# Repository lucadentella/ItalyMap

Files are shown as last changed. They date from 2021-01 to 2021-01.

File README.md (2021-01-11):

# ItalyMap
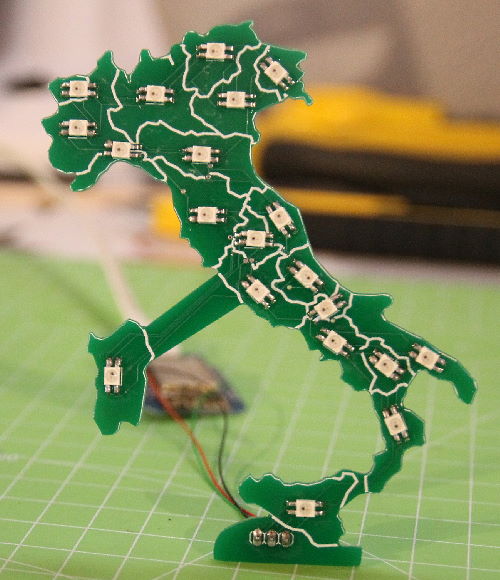
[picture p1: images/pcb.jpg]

## Description / *Descrizione*
ItalyMap is an electronic project to create a dynamic map of Italy. Thanks to the use of RGB LEDs, one for each Italian region, it is possible to give a visual representation of data relating to these regions.

*ItalyMap è un progetto elettronico per realizzare una mappa dell'Italia dinamica. Grazie all'uso di led RGB, uno per ogni regione italiana, è possibile dare una rappresentazione visuale di dati relativi a tali regioni.*
## Folders / *Cartelle*
 - **eagle**, project in Autodesk Eagle format / *progetto in formato Autodesk Eagle*
 - **gerber**, gerber files ready for manufacturing (JLCPCB service) / *files gerber pronti per la produzione (service JLCPCB)*
 - **sketch**, Arduino programs (esp8266 board) / *programmi Arduino (scheda esp8266)*
 	 - Test_Italian-Flag, displays italian flag / *visualizza la bandiera italiana*
	 - Covid_NewCases-perRegion, displays the new Covid-19 cases / *visualizza i nuovi casi di Covid-19*
	 - Covid_VaccinationRate-perRegion, displays the vaccination rate / *visualizza il numero di vaccinazioni*
## Partlist / *Elenco componenti*
 - [SK6812 MINI-E](https://www.aliexpress.com/item/4000475685852.html) addressable LED
 - 1x03 pinhead
 - Wemos D1 Mini (to run Arduino example)
### Test_Italian-Flag:
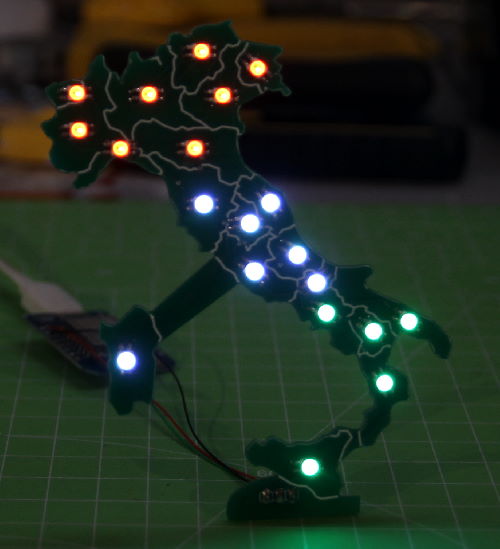
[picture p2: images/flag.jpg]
 
### Covid_NewCases-perRegion:
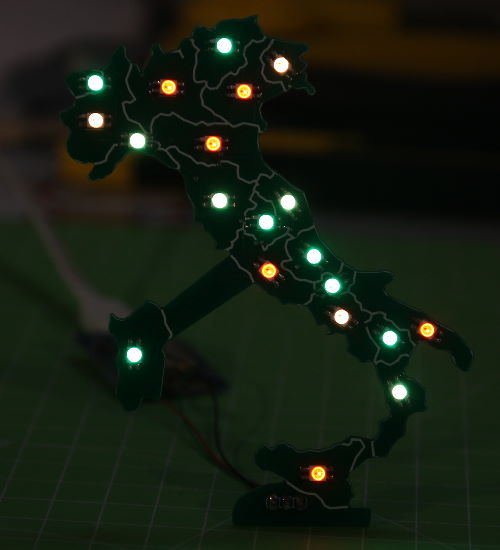
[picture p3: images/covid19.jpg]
 
### Covid_VaccinationRate-perRegion:
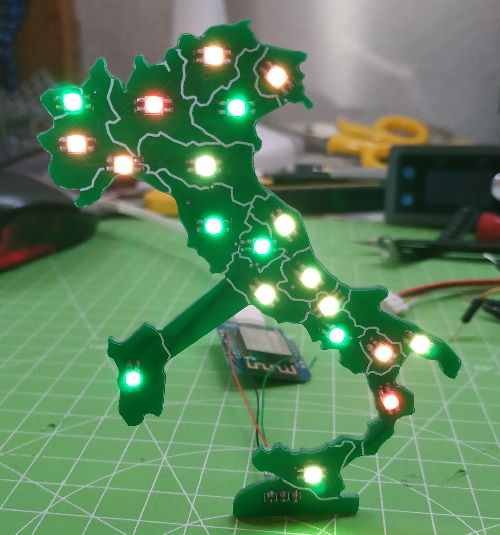
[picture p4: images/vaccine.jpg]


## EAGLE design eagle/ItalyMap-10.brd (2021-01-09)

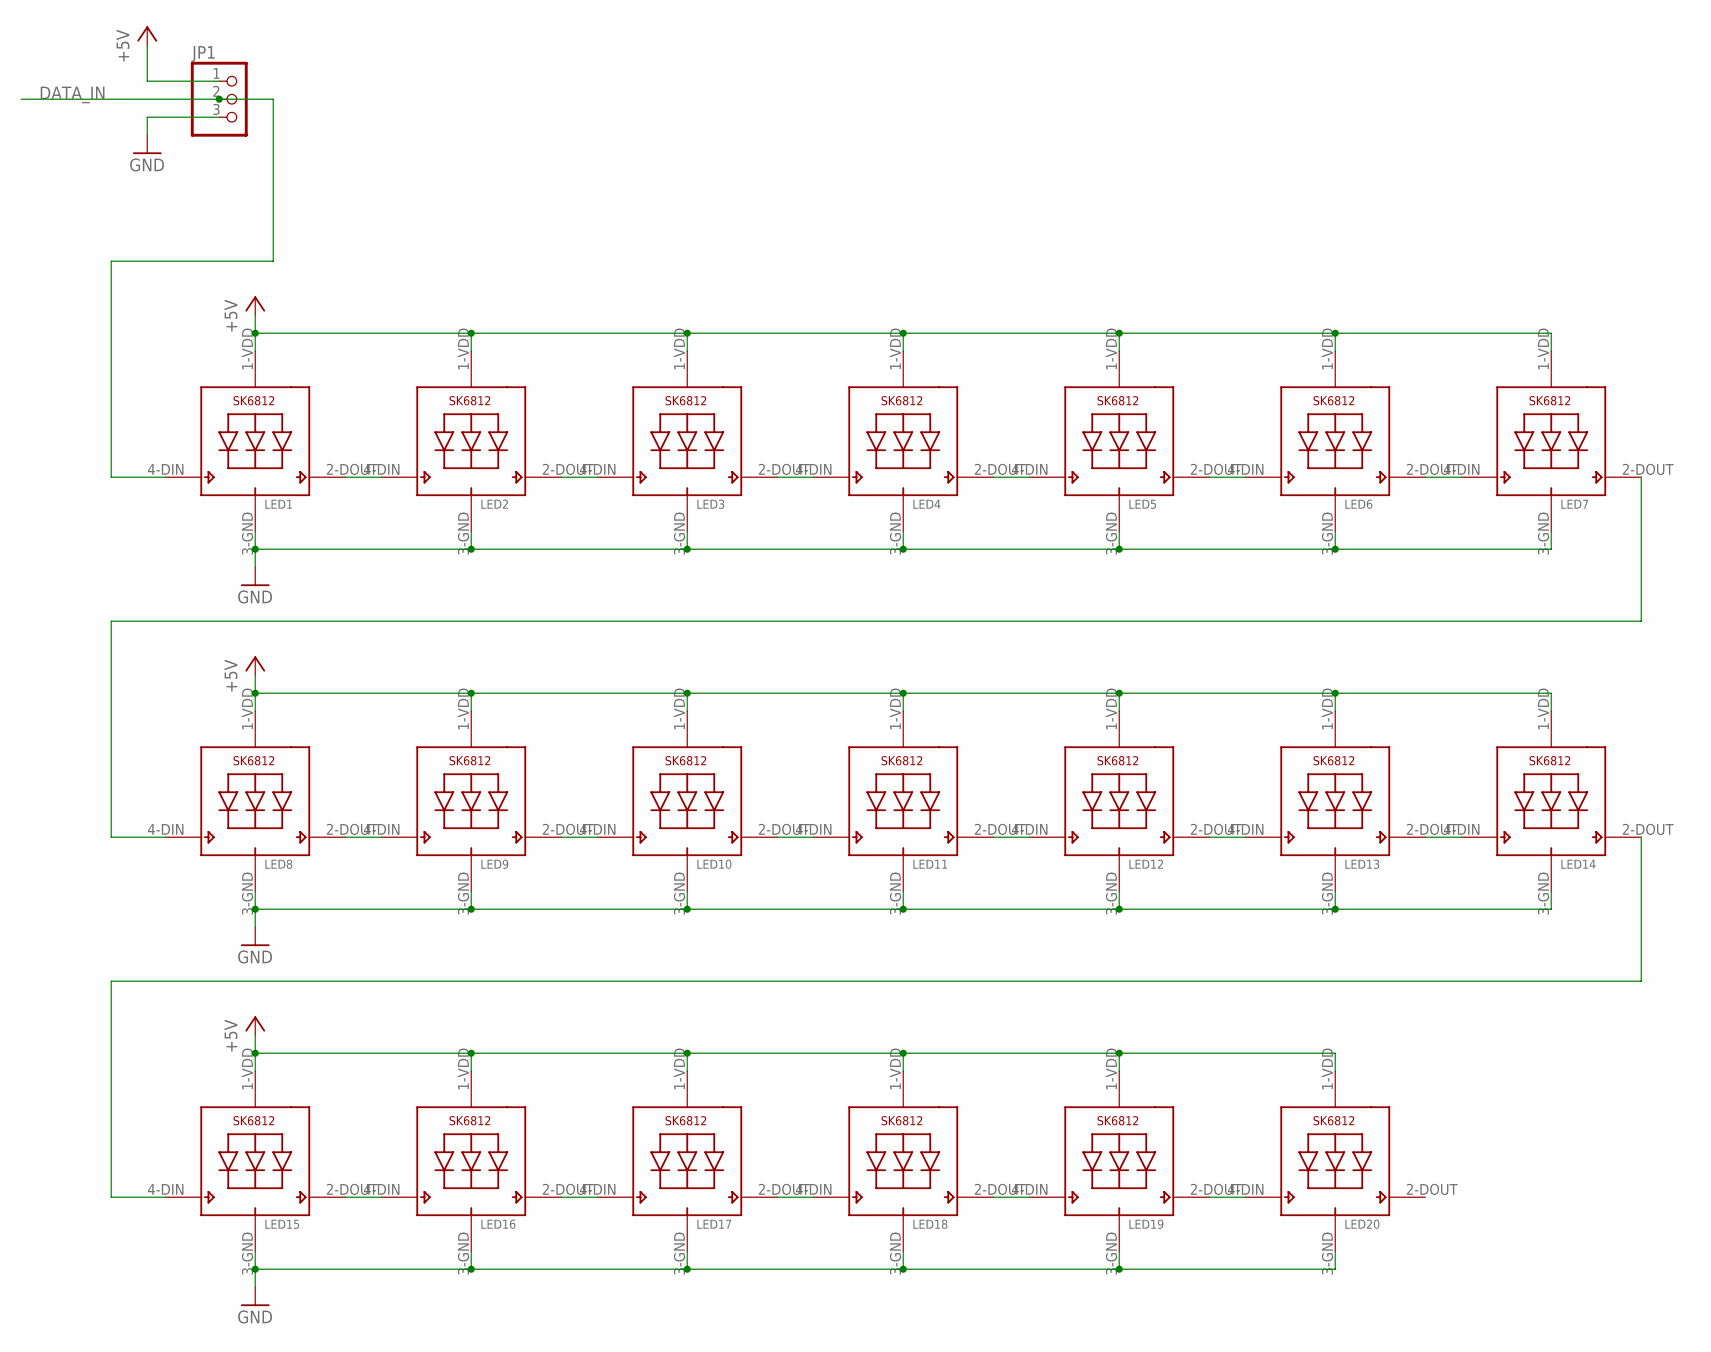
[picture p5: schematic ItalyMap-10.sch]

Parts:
JP1: PINHD-1X3; 1X03
LED1, LED2, LED3, LED4, LED5, LED6, LED7, LED8, LED9, LED10, LED11, LED12, LED13, LED14, LED15, LED16, LED17, LED18, LED19, LED20: SK6812; LED3228

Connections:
+5V: JP1.1, LED1.1-VDD (VDD), LED2.1-VDD (VDD), LED3.1-VDD (VDD), LED4.1-VDD (VDD), LED5.1-VDD (VDD), LED6.1-VDD (VDD), LED7.1-VDD (VDD), LED8.1-VDD (VDD), LED9.1-VDD (VDD), LED10.1-VDD (VDD), LED11.1-VDD (VDD), LED12.1-VDD (VDD), LED13.1-VDD (VDD), LED14.1-VDD (VDD), LED15.1-VDD (VDD), LED16.1-VDD (VDD), LED17.1-VDD (VDD), LED18.1-VDD (VDD), LED19.1-VDD (VDD), LED20.1-VDD (VDD)
DATA_IN: JP1.2, LED1.4-DIN (DI)
GND: JP1.3, LED1.3-GND (GND), LED2.3-GND (GND), LED3.3-GND (GND), LED4.3-GND (GND), LED5.3-GND (GND), LED6.3-GND (GND), LED7.3-GND (GND), LED8.3-GND (GND), LED9.3-GND (GND), LED10.3-GND (GND), LED11.3-GND (GND), LED12.3-GND (GND), LED13.3-GND (GND), LED14.3-GND (GND), LED15.3-GND (GND), LED16.3-GND (GND), LED17.3-GND (GND), LED18.3-GND (GND), LED19.3-GND (GND), LED20.3-GND (GND)
unnamed: LED7.2-DOUT (DO), LED8.4-DIN (DI)
unnamed: LED1.2-DOUT (DO), LED2.4-DIN (DI)
unnamed: LED2.2-DOUT (DO), LED3.4-DIN (DI)
unnamed: LED3.2-DOUT (DO), LED4.4-DIN (DI)
unnamed: LED4.2-DOUT (DO), LED5.4-DIN (DI)
unnamed: LED5.2-DOUT (DO), LED6.4-DIN (DI)
unnamed: LED6.2-DOUT (DO), LED7.4-DIN (DI)
unnamed: LED8.2-DOUT (DO), LED9.4-DIN (DI)
unnamed: LED9.2-DOUT (DO), LED10.4-DIN (DI)
unnamed: LED10.2-DOUT (DO), LED11.4-DIN (DI)
unnamed: LED11.2-DOUT (DO), LED12.4-DIN (DI)
unnamed: LED12.2-DOUT (DO), LED13.4-DIN (DI)
unnamed: LED13.2-DOUT (DO), LED14.4-DIN (DI)
unnamed: LED14.2-DOUT (DO), LED15.4-DIN (DI)
unnamed: LED15.2-DOUT (DO), LED16.4-DIN (DI)
unnamed: LED16.2-DOUT (DO), LED17.4-DIN (DI)
unnamed: LED17.2-DOUT (DO), LED18.4-DIN (DI)
unnamed: LED18.2-DOUT (DO), LED19.4-DIN (DI)
unnamed: LED19.2-DOUT (DO), LED20.4-DIN (DI)

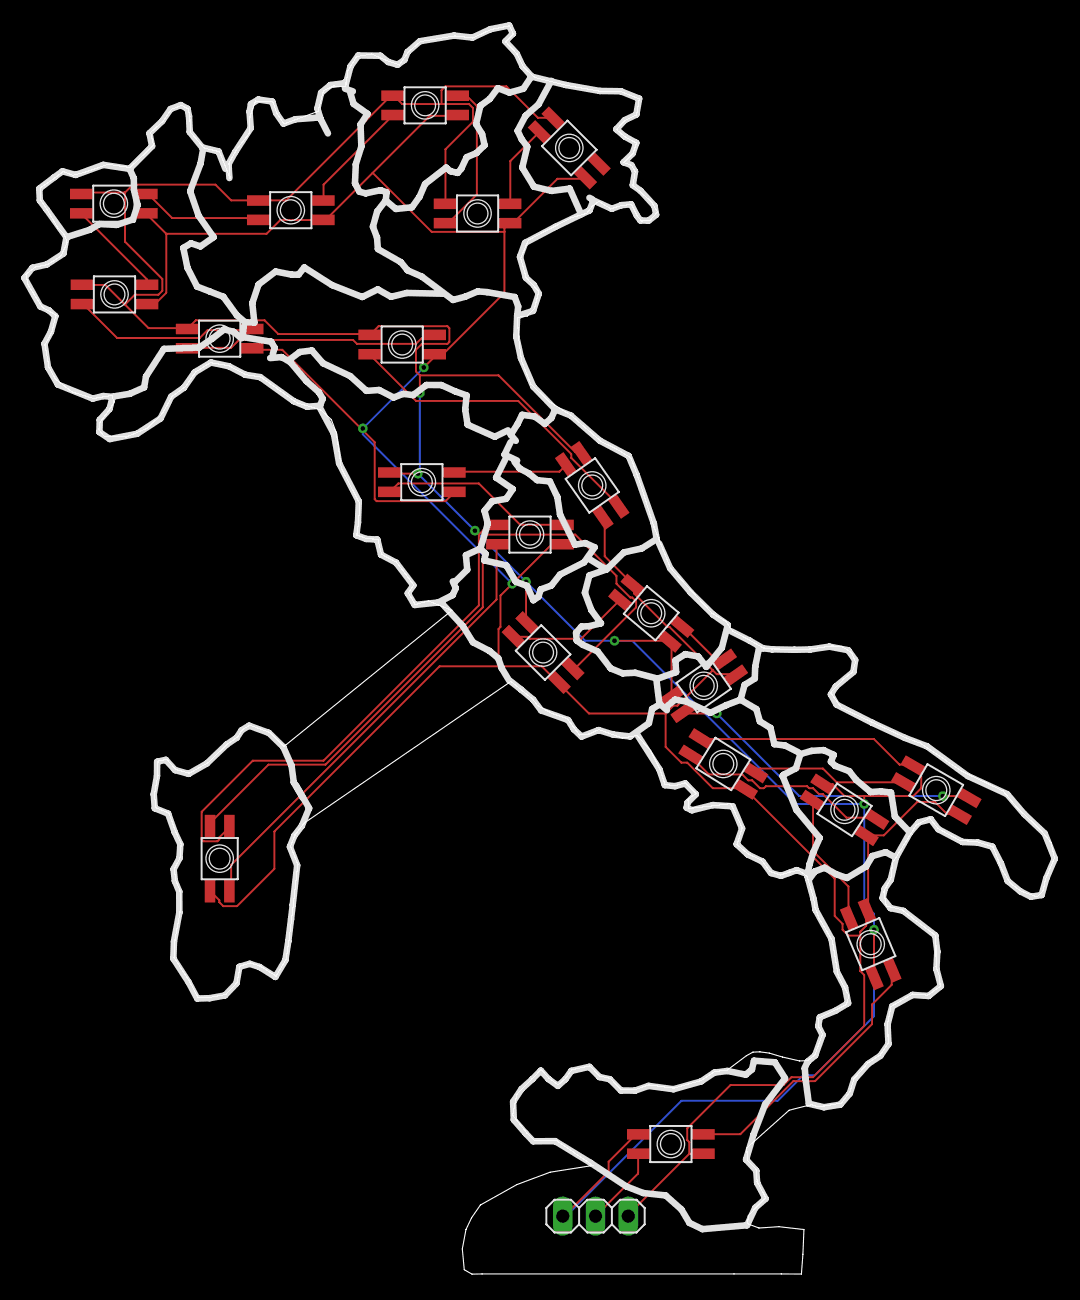
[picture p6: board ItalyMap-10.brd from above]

Board: 2 copper layers, 79.7 x 96.8 mm, 21 parts (0 on the bottom side), 22 nets.

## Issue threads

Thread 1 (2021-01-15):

Add license information

vazhnov, 2021-01-15:
Hello!

I found link to this project from https://hackaday.com/2021/01/14/dynamic-map-of-italy-on-a-pcb/

Could you please add information about license of this repository — is it allowed to copy, change and use the code and board schematic files in any purpose?
It would be great to see any popular open source license.

lucadentella, 2021-01-15:
Hi Alexey!

thanks for reminding me of this: this are educational projects so I often forget to explicitly indicate the license.
I normally go for **CC BY 4.0**

vazhnov, 2021-01-15:
Great! Thank you!

Closed 2021-01-15.

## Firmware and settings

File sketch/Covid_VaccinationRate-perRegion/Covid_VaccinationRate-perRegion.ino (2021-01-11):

#include <ESP8266WiFi.h>
#include <WiFiClientSecure.h>
#include <Adafruit_NeoPixel.h>

#define NUM_REGIONS 20
String pixelRegione[NUM_REGIONS] = {"SIC", "CAL", "BAS", "CAM", "PUG", "MOL", "ABR", "LAZ", "SAR", "UMB", "TOS", "MAR", "EMR", "LIG", "PIE", "VDA", "LOM", "TAA", "VEN", "FVG"};

const char* ssid     = "MySSID";
const char* password = "MyPwd";
const char* csvHost  = "raw.githubusercontent.com";
const int csvPort    = 443;
const char* csvURL   = "/italia/covid19-opendata-vaccini/master/dati/vaccini-summary-latest.csv";

#define SIGNAL_PIN  14
Adafruit_NeoPixel strip(NUM_REGIONS, SIGNAL_PIN, NEO_GRB + NEO_KHZ800);

#define GREEN_TH    80.0
#define YELLOW_TH   60.0
#define ORANGE_TH   50.0

uint32_t red = strip.Color(255, 0, 0);
uint32_t orange = strip.Color(255, 60, 0);
uint32_t yellow = strip.Color(255, 230, 0);
uint32_t green = strip.Color(0, 255, 0);

#define UPDATE_INTERVAL 600
unsigned long lastUpdateTime = 0;

void setPixelColor(String region, int percentage) {

  // get the led corresponding to the region
  int ledNum = -1;
  for(int i = 0; i < NUM_REGIONS; i++)
    if(region == pixelRegione[i]) {
      ledNum = i;
      break;
    }
  
  if(percentage > GREEN_TH) strip.setPixelColor(ledNum, green);
  else if(percentage > YELLOW_TH) strip.setPixelColor(ledNum, yellow);  
  else if(percentage > ORANGE_TH) strip.setPixelColor(ledNum, orange);
  else strip.setPixelColor(ledNum, red); 
}

void updateMap() {

  Serial.println();
  Serial.println("------------ Updating Map ------------");

  WiFiClientSecure httpsClient;
  httpsClient.setInsecure();

  // file contains two values for Trentino Alto Adige
  float trentinoAvg = 0;
  
  if(!httpsClient.connect(csvHost, csvPort)) {
    Serial.println("Unable to connect to Github :(");
    return;
  }
  Serial.println("Connected to Github");
  httpsClient.print(String("GET ") + csvURL + " HTTP/1.1\r\n" +
    "Host: " + csvHost + "\r\n" +
    "Connection: close\r\n\r\n");
  
  // download all the headers
  while (httpsClient.connected()) {
    String line = httpsClient.readStringUntil('\n');
    if (line == "\r") break;
  }

  // download first line (column headers)
  String line = httpsClient.readStringUntil('\n');

  // download all the lines
  while(httpsClient.available()) {
    
    // get line and convert into char array (for strtok)
    String line = httpsClient.readStringUntil('\n');
    char buf[line.length()];
    line.toCharArray(buf, sizeof(buf));

    // divide the line into tokens (comma-separated)
    char *p = buf;
    char *str;
    int tokenCount = 0;
    String regionCode;
    float regionPercentage;
    
    // extract region code and number of new cases
    while ((str = strtok_r(p, ",", &p)) != NULL) {
      tokenCount++;
      if(tokenCount == 1) regionCode = String(str);
      else if(tokenCount == 4) regionPercentage = atof(str); 
    }

    // average P.A. Bolzano and P.A. Trento
    if(regionCode == "PAB") {
      trentinoAvg = regionPercentage;
      continue;
    }
    else if(regionCode == "PAT") {
      trentinoAvg = (trentinoAvg + regionPercentage) / 2;
      regionPercentage = trentinoAvg;
      regionCode = "TAA";
    }
    Serial.print("Region: ");
    Serial.print(regionCode);
    Serial.print(", percentage: ");
    Serial.println(regionPercentage);

    setPixelColor(regionCode, regionPercentage);
  }
  strip.show();
  Serial.println("Pixel colors updated");
}


void setup() {

  Serial.begin(115200);
  Serial.println("ItalyMap - Covid New Cases per Region");
  Serial.println();
  
  strip.begin();
  strip.setBrightness(5);
  strip.clear();
  Serial.println("NeoPixel library init DONE");
 
  WiFi.mode(WIFI_STA);
  WiFi.begin(ssid, password);
  Serial.println("WiFi init DONE");
  
  while (WiFi.status() != WL_CONNECTED) {
    delay(100);
  }
  Serial.print("Connected to ");
  Serial.println(ssid);

  updateMap();
}

void loop() {

  if(millis() > lastUpdateTime + (UPDATE_INTERVAL * 1000)) {
    updateMap();
    lastUpdateTime = millis();
  }
}

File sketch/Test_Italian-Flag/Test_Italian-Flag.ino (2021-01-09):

#include <Adafruit_NeoPixel.h>

#define NUM_REGIONS 20
#define SIGNAL_PIN  14
Adafruit_NeoPixel strip(NUM_REGIONS, SIGNAL_PIN, NEO_GRB + NEO_KHZ800);

uint32_t red = strip.Color(255, 0, 0);
uint32_t green = strip.Color(0, 255, 0);
uint32_t orange = strip.Color(255, 60, 0);
uint32_t blue = strip.Color(0, 0, 255);
uint32_t white = strip.Color(255, 255, 255);

void setup() {
  
  strip.begin();
  strip.setBrightness(5);
  strip.clear();
}

void loop() {

  for(int i = 0; i < NUM_REGIONS; i++) {
    strip.setPixelColor(i, orange);
    strip.show();
    delay(50);
  }
  delay(500);
  strip.clear();

  for(int i = NUM_REGIONS - 1; i >= 0; i--) {
    strip.setPixelColor(i, blue);
    strip.show();
    delay(50);
  }
  delay(500);
  strip.clear();


  for(int i = 0; i < 5; i++) strip.setPixelColor(i, green);
  for(int i = 5; i < 12; i++) strip.setPixelColor(i, white);
  for(int i = 12; i < NUM_REGIONS; i++) strip.setPixelColor(i, red); 
  strip.show();
  delay(3000);

  strip.clear();
  delay(500);
}

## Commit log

2021-01-09 Arduino sketches
2021-01-09 Eagle and gerber files added
    [ItalyMap-10.brd, ItalyMap-10.sch]
